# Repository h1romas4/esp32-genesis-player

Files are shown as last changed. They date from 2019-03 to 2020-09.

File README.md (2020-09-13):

# esp32-genesis-player

Work in progress..

## Demo

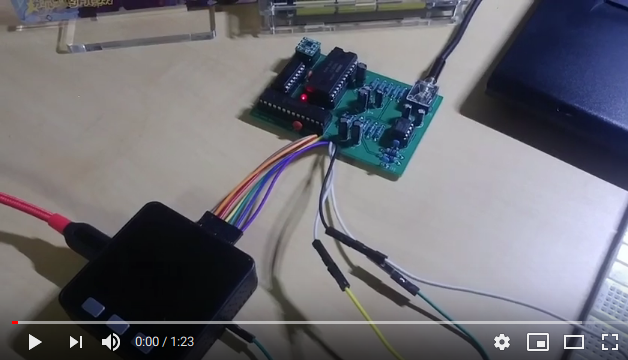
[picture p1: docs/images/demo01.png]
demo (https://youtu.be/mzKiQgvpdTA)


## Require

* ESP32 (ESP32-DevKitC, M5Stack...)
* [esp32-idf toolchain setup](https://docs.espressif.com/projects/esp-idf/en/stable/get-started/index.html#setup-toolchain)

```
$ xtensa-esp32-elf-gcc -v
gcc version 5.2.0 (crosstool-NG crosstool-ng-1.22.0-80-g6c4433a)
```

## Build



```
git clone  --recursive https://github.com/h1romas4/esp32-genesis-player.git
cd esp32-genesis-player
# This repository includes eps-idf v3.3.3
export IDF_PATH=$(pwd)/esp-idf
# Serial flasher config
make menuconfig
# compile & flash
make flash
```

## Upload .vgm file to esp32 flash

```
# mv example.vgz example.vgm.gz
# gzip -d example.vgm.gz
./flashrom.sh vgm/kanon2612.vgm
```

## Schematic

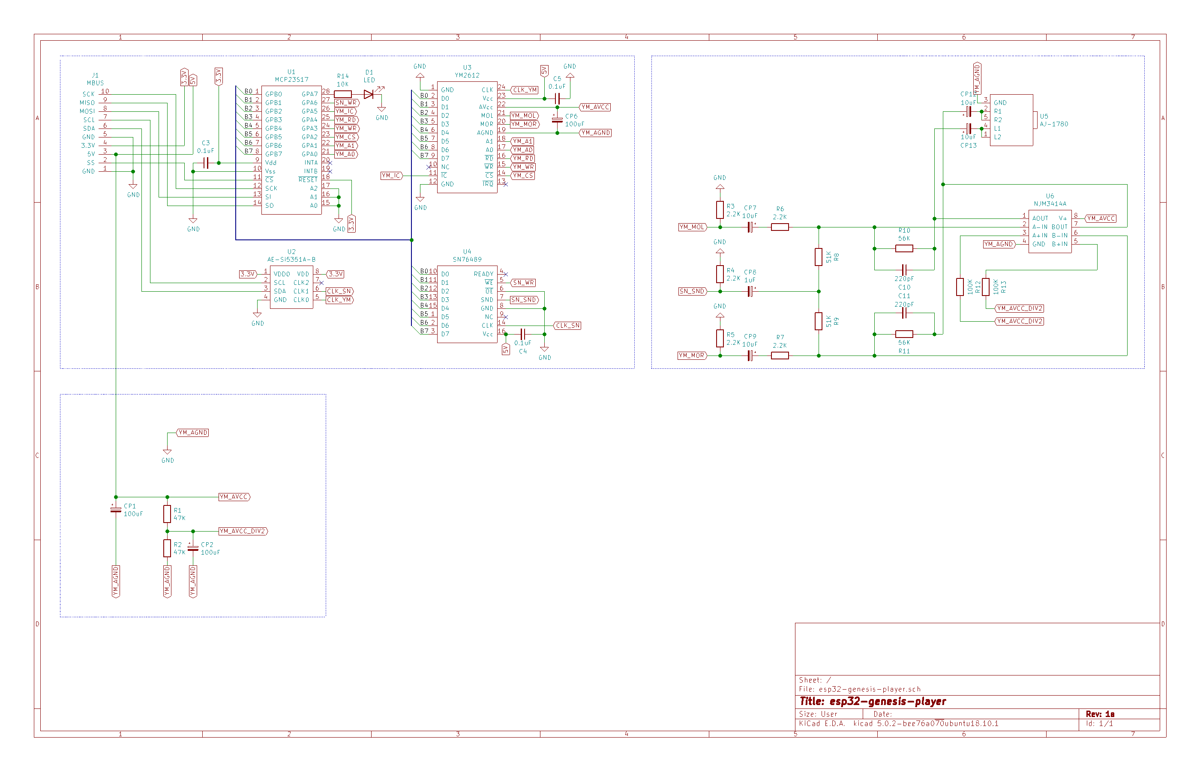
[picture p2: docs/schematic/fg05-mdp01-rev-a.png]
fg05-mdp01-rev-a


### ESP32 (MBUS)

```
ESP32 GPIO(23) VSPI MOSI     MCP23S17(13) SI
ESP32 GPIO(19) VSPI MISO     MCP23S17(14) SO
ESP32 GPIO(18) VSPI SCK      MCP23S17(12) SCK
ESP32 GPIO( 5) VSPI SS       MCP23S17(11) CS
ESP32 GPIO(22) SCL           Si5351A(2)  SCL
ESP32 GPIO(21) SDA           Si5351A(3)  SDA
```

### MCP23S17

```
IC( 9) Vdd             3.3V
IC(10) Vss             GND
IC(15) A0              GND
IC(16) A1              GND
IC(17) A2              GND
IC(18) RESET           3.3V
IC(19) INTA            (NC)
IC(29) INTB            (NC)
```

## Si5351A ([AE-Si5351A-B](http://akizukidenshi.com/catalog/g/gK-10679/))

```
DIP(1) VDD0            3.3V
DIP(4) GND             GND
DIP(7) CLK2            (NC)
DIP(8) VDD             3.3V
```

### YM2612

```
IC( 1) GND            GND
IC( 2) D0             MCP23S17( 1)  GPB0
IC( 3) D1             MCP23S17( 2)  GPB1
IC( 4) D2             MCP23S17( 3)  GPB2
IC( 5) D3             MCP23S17( 4)  GPB3
IC( 6) D4             MCP23S17( 5)  GPB4
IC( 7) D5             MCP23S17( 6)  GPB5
IC( 8) D6             MCP23S17( 7)  GPB6
IC( 9) D7             MCP23S17( 8)  GPB7
IC(10) NC             (NC)
IC(11) ~IC            MCP23S17(26)  GPA5
IC(12) GND            GND
IC(13) ~IRQ           (NC)
IC(14) ~CS            MCP23S17(23)  GPA2
IC(15) ~WR            MCP23S17(24)  GPA3
IC(16) ~RD            MCP23S17(25)  GPA4
IC(17) A0             MCP23S17(21)  GPA0
IC(18) A1             MCP23S17(22)  GPA1
IC(19) AGND           GND
IC(20) MOR            (audio R)
IC(21) MOL            (audio L)
IC(22) AVcc           5V - 100uf bypass capacitor
IC(23) Vcc            5V - 0.1uF bypass capacitor
IC(24) CLK            Si5351A(5) CLK0
```

### SN76489

```
IC( 1) D5             MCP23S17( 6)  GPB5
IC( 2) D6             MCP23S17( 7)  GPB6
IC( 3) D7             MCP23S17( 8)  GPB7
IC( 4) READY          (NC)
IC( 5) ~WE            MCP23S17(27)  GPA6
IC( 6) ~CE            GND
IC( 7) SNDOUT         (audio L/R)
IC( 8) GND            GND
IC( 9) NC             (NC)
IC(10) D0             MCP23S17( 1)  GPB0
IC(11) D1             MCP23S17( 2)  GPB1
IC(12) D2             MCP23S17( 3)  GPB2
IC(13) D3             MCP23S17( 4)  GPB3
IC(14) CLK            Si5351A(6) CLK1
IC(15) D4             MCP23S17( 5)  GPB4
IC(16) Vcc            5V
```

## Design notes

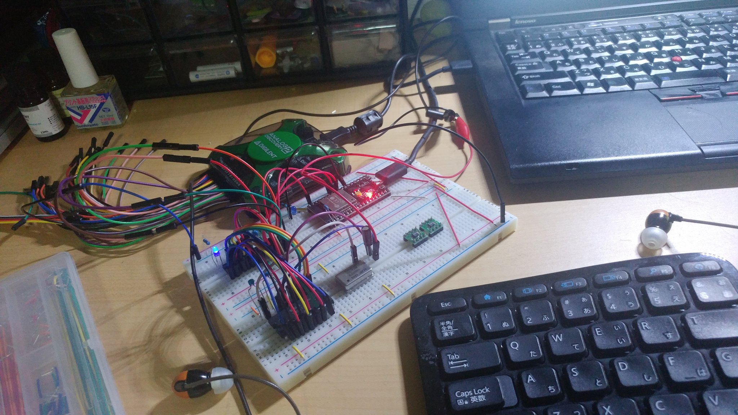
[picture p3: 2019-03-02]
docs/images/progress01.jpg

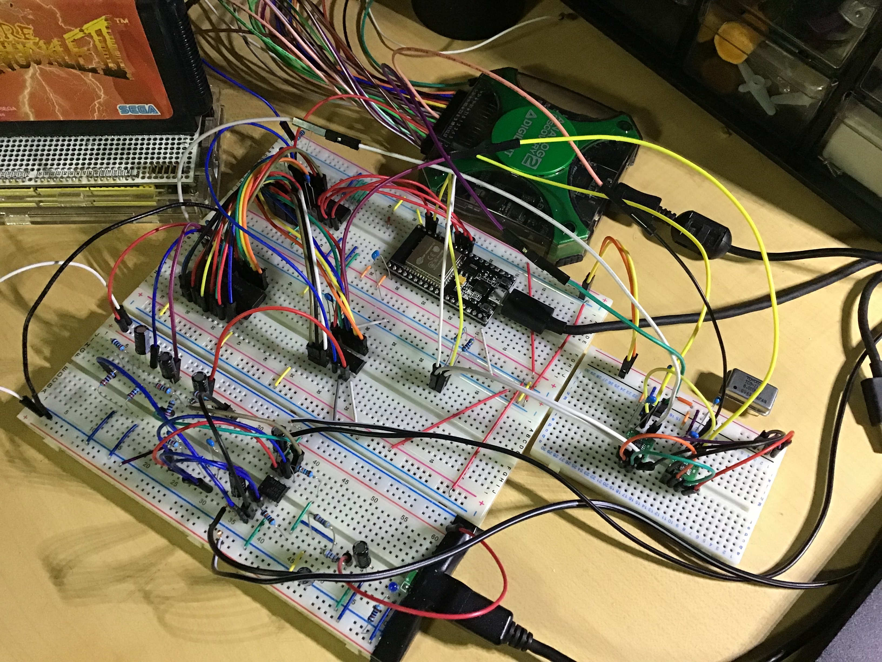
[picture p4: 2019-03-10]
docs/images/progress02.jpg

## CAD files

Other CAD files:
docs/blender/22uh.blend
docs/blender/30pin.blend
docs/blender/AJ-1780.blend
docs/blender/BNX016-01.blend
docs/blender/KMR-18.blend
docs/blender/TS-0606.blend
docs/blender/lock.blend

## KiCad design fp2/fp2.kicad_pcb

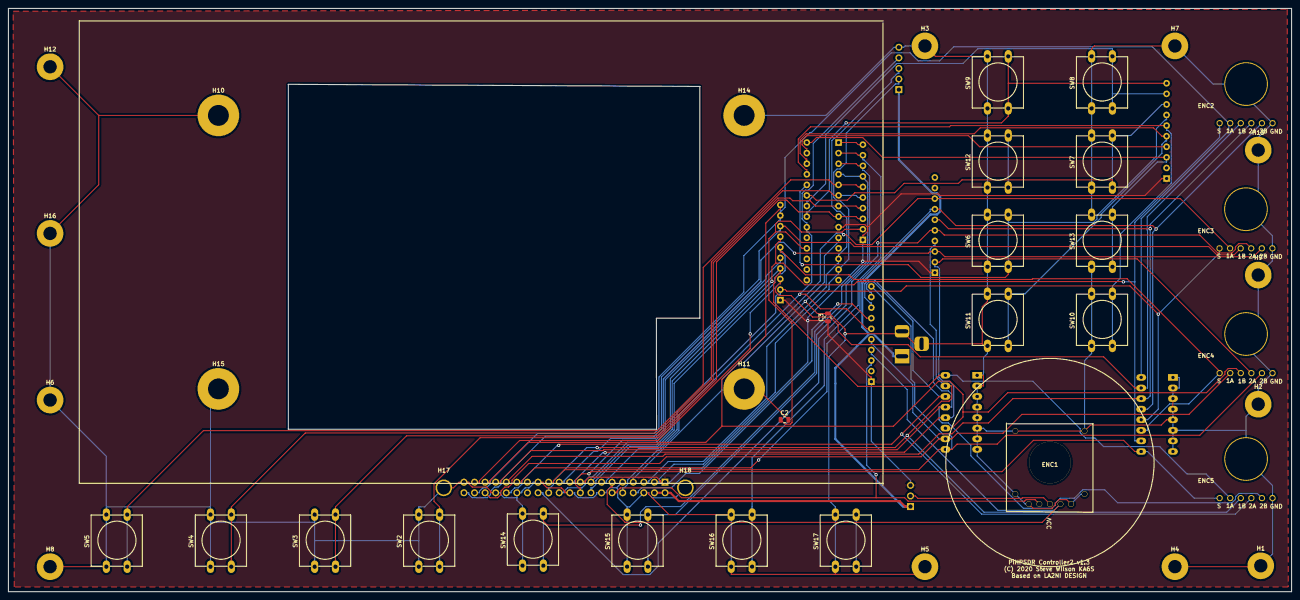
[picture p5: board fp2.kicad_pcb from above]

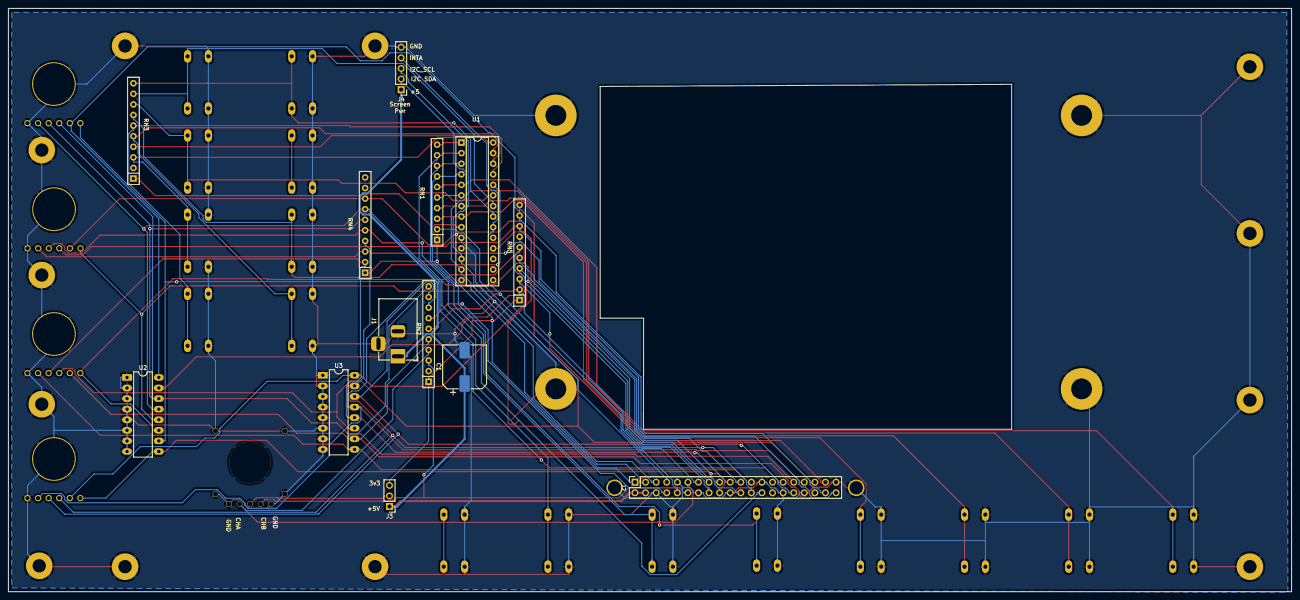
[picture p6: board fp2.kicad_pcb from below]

Board: 2 copper layers, 308.0 x 140.0 mm, 54 parts (13 on the bottom side), 47 nets.

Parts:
C1: 220uF; CP_Elec_10x10
C2: 0.01uF; C_0805_2012Metric
C3: 10uF; C_0805_2012Metric
ENC1: Rotary_Encoder_HRPG
ENC2, ENC3, ENC4, ENC5: rotary_encoder_elma37a; ELMA_E37A
H1, H2, H3, H4, H5, H6, H7, H8, H9, H12, H13, H16, H17, H18: MountingHole_Pad; MountingHole_3.2mm_M3_Pad
H10, H11, H14, H15: MountingHole_Pad; MountingHole_5mm_Pad
J1: Barrel_Jack_MountingPin; BarrelJack_Horizontal
J2: Conn_02x20_Odd_Even; PinSocket_2x20_P2.54mm_Vertical
J3: Conn_01x03; PinHeader_1x03_P2.54mm_Vertical
J4: Conn_01x05; PinHeader_1x05_P2.54mm_Vertical
RN1, RN2, RN3, RN4, RN5: 10K; R_Array_SIP10
SW2, SW3, SW4, SW5, SW6, SW7, SW8, SW9, SW10, SW11, SW12, SW13, SW14, SW15, SW16, SW17: SW_SPST; SW_PUSH-12mm
U1: MCP23017_SO; DIP-28_W7.62mm_Socket
U2, U3: 0.01uF ARRAY; CAP_ARRAY_16

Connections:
/encoder/3V3: C3.1, J2.1, J2.17, J3.3, RN1.1, RN2.1, RN3.1, RN4.1, RN5.1, U1.9
/encoder/5V: C1.1, J1.1, J2.2, J2.4, J3.1, J4.1
/encoder/GBP0: RN1.10, U1.1
/encoder/GPA0: RN3.10, SW9.2, U1.21
/encoder/GPA1: RN3.9, SW8.2, U1.22
/encoder/GPA2: RN3.8, SW7.2, U1.23
/encoder/GPA3: RN3.7, SW6.2, U1.24
/encoder/GPA4: RN3.6, SW10.2, U1.25
/encoder/GPA5: RN3.5, SW11.2, U1.26
/encoder/GPA6': RN3.4, U1.27
/encoder/GPA7: RN3.3, SW13.2, U1.28
/encoder/GPB1: RN1.9, SW16.2, U1.2
/encoder/GPB2: RN1.8, SW15.2, U1.3
/encoder/GPB3: RN1.7, SW14.2, U1.4
/encoder/GPB4: RN1.6, SW5.2, U1.5
/encoder/GPB5: RN1.5, SW4.2, U1.6
/encoder/GPB6: RN1.4, SW3.2, U1.7
/encoder/GPB7: RN1.3, SW2.2, U1.8
/encoder/GPIO4: ENC3.2, J2.7, RN4.8
/encoder/GPIO5: ENC2.5, J2.29, RN4.7, U2.13
/encoder/GPIO6: ENC2.4, J2.31, RN4.6, U2.14
/encoder/GPIO7: ENC3.4, J2.26, RN4.5
/encoder/GPIO8: ENC5.3, J2.24, RN4.4, U3.15
/encoder/GPIO9: ENC3.5, J2.21, RN4.3
/encoder/GPIO10: ENC4.4, J2.19, RN4.2, U3.12
/encoder/GPIO11: ENC4.5, J2.23, RN2.10, U3.9
/encoder/GPIO12: ENC5.4, J2.32, RN2.9, U3.14
/encoder/GPIO13: ENC5.5, J2.33, RN2.8, U3.13
/encoder/GPIO14: J2.8, RN2.7
/encoder/GPIO15: J2.10, J4.4, RN2.6, U1.20
/encoder/GPIO16: ENC4.2, J2.36, RN2.5, U3.10
/encoder/GPIO17: ENC1.2, J2.11, RN2.4
/encoder/GPIO18: ENC1.4, J2.12, RN2.3
/encoder/GPIO19: ENC4.3, J2.35, RN5.10, U3.11
/encoder/GPIO20: ENC2.2, J2.38, RN5.9, U2.16
/encoder/GPIO21: ENC3.3, J2.40, RN5.8
/encoder/GPIO22: ENC2.1, J2.15, RN5.7, U2.10
/encoder/GPIO23: ENC4.1, J2.16, RN5.6, U2.11
/encoder/GPIO24: ENC5.1, J2.18, RN5.5, U2.9
/encoder/GPIO25: ENC5.2, J2.22, RN5.4, U3.16
/encoder/GPIO26: ENC2.3, J2.37, RN5.3, U2.15
/encoder/GPIO27: ENC3.1, J2.13, RN5.2, U2.12
/encoder/I2C_SCL: J2.5, J4.3, U1.12
/encoder/I2C_SDA: J2.3, J4.2, U1.13
GND: C1.2, C2.2, C3.2, ENC1.1, ENC1.5, ENC2.6, ENC3.6, ENC4.6, ENC5.6, H1.1, H2.1, H3.1, H4.1, H5.1, H6.1, H7.1, H8.1, H9.1, H10.1, H11.1, H12.1, H13.1, H14.1, H15.1, H16.1, H17.1, H18.1, J1.2, J1.MP, J2.6, J2.9, J2.14, J2.20, J2.25, J2.30, J2.34, J2.39, J4.5, SW2.1, SW3.1, SW4.1, SW5.1, SW6.1, SW7.1, SW8.1, SW9.1, SW10.1, SW11.1, SW12.1, SW13.1, SW14.1, SW15.1, SW16.1, SW17.1, U1.10, U2.1, U2.2, U2.3, U2.4, U2.5, U2.6, U2.7, U2.8, U3.1, U3.2, U3.3, U3.4, U3.5, U3.6, U3.7, U3.8
unnamed: C2.1, RN1.2, U1.18
unnamed: ENC1.3, J3.2

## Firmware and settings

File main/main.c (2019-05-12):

#include <string.h>
#include "freertos/FreeRTOS.h"
#include "freertos/task.h"
#include "nvs_flash.h"
#include "esp_system.h"
#include "esp_log.h"
#include "esp_partition.h"
#include "esp_heap_caps.h"
#include "esp_timer.h"
#include "chips.h"

// for vscode c_cpp_extention
#ifdef __INTELLISENSE__
#include "build/include/sdkconfig.h"
#endif

#define SAMPLE_RATE 44100.0

static const char *TAG = "vgmplay";

// uint8_t *vgm;
uint8_t *vgm;
uint32_t vgmpos = 0x40;
bool vgmend = false;
uint32_t vgmloopoffset;
uint32_t datpos;
uint32_t pcmpos;
uint32_t pcmoffset;
uint32_t pcmlength = 0;

int64_t startTime;
int64_t duration;
uint32_t delay8n[16];
uint32_t delay7n[16];

int64_t startTimePCM;
int64_t durationPCM;

void load_vgmdata()
{
    uint8_t *data;
    const esp_partition_t *part;
    spi_flash_mmap_handle_t hrom;
    esp_err_t err;

    nvs_flash_init();

    part = esp_partition_find_first(ESP_PARTITION_TYPE_DATA, ESP_PARTITION_SUBTYPE_DATA_PHY, NULL);
    if (part == 0) {
        ESP_LOGE(TAG, "Couldn't find vgm part!");
    }

    err = esp_partition_mmap(part, 0, 0x1EF000, SPI_FLASH_MMAP_DATA, (const void **)&data, &hrom);
    if (err != ESP_OK) {
        ESP_LOGE(TAG, "Couldn't map vgm part!");
    }
    ESP_LOGI(TAG, "read vgm data @%p", data);

    // // for testing..
    // vgm = (uint8_t *)heap_caps_malloc(100000 * sizeof(uint8_t), MALLOC_CAP_8BIT);
    // if(vgm == NULL) {
    //     ESP_LOGE(TAG, "Memory alloc error");
    // }
    // memcpy(vgm, data, 100000);
    // // vgm = (uint8_t *)data;

    vgm = (uint8_t *)data;
}

uint8_t get_vgm_ui8()
{
    return vgm[vgmpos++];
}

uint16_t get_vgm_ui16()
{
    return get_vgm_ui8() + (get_vgm_ui8() << 8);
}

uint32_t get_vgm_ui32()
{
    return get_vgm_ui8() + (get_vgm_ui8() << 8) + (get_vgm_ui8() << 16) + (get_vgm_ui8() << 24);
}

void init_vgm(chips_t *chips)
{
    uint32_t clock_sn76489;
    uint32_t clock_ym2612;

    // load vgm data
    load_vgmdata();

    // read vgm header
    vgmpos = 0x0C; clock_sn76489 = get_vgm_ui32();
    vgmpos = 0x2C; clock_ym2612 = get_vgm_ui32();
    vgmpos = 0x1c; vgmloopoffset = get_vgm_ui32();
    vgmpos = 0x34; vgmpos = 0x34 + get_vgm_ui32();

    if (clock_ym2612 == 0) clock_ym2612 = 7670453;
    if (clock_sn76489 == 0) clock_sn76489 = 3579545;

    chips->clock_ym2612 = clock_ym2612;
    chips->clock_sn76489 = clock_sn76489;

    ESP_LOGI(TAG, "clock_sn76489 : %d", clock_sn76489);
    ESP_LOGI(TAG, "clock_ym2612 : %d", clock_ym2612);
    ESP_LOGI(TAG, "vgmpos : 0x%x", vgmpos);

    // pre calc delay sample.
    for (int i = 0; i < 16; i++) {
        if (i == 0) {
            delay8n[i] = 0;
            delay7n[i] = 1;
        } else {
            delay8n[i] = ((1000.0 / (SAMPLE_RATE / (float)i)) * 1000);
            // +1 is spec-accurate; however, on this hardware, it sounds better without it.
            delay7n[i] = ((1000.0 / (SAMPLE_RATE / (float)i + 1)) * 1000);
        }
    }
}

void pause(uint32_t samples)
{
    duration = ((1000.0 / (SAMPLE_RATE / (float)samples)) * 1000);
    startTime = esp_timer_get_time();
}

void pause_ms(uint32_t ms)
{
    duration = ms;
    startTime = esp_timer_get_time();
}

void pause_pcm(uint32_t samples)
{
    durationPCM = ((1000.0 / (SAMPLE_RATE / (float)samples)) * 1000);
    startTimePCM = esp_timer_get_time();
}

void play_vgm()
{
    uint8_t command;
    uint8_t reg;
    uint8_t dat;

    // TODO: mucomMD2vgm hack
    if(pcmlength > 0 && esp_timer_get_time() - startTimePCM > durationPCM) {
        pause_pcm(5.5125);
        YM2612_Write(0, 0x2a);
        YM2612_Write(1, vgm[datpos + pcmpos + pcmoffset]);
        pcmoffset++;
        pcmlength--;
    }

    // wait play
    if (esp_timer_get_time() - startTime <= duration) {
        return;
    }

    command = get_vgm_ui8();
    switch (command) {
        case 0x50:
            dat = get_vgm_ui8();
            SN76489_Write(dat);
            break;
        case 0x52:
        case 0x53:
            reg = get_vgm_ui8();
            dat = get_vgm_ui8();
            YM2612_Write(0 + ((command & 1) << 1), reg);
            YM2612_Write(1 + ((command & 1) << 1), dat);
            break;
        case 0x61:
            pause(get_vgm_ui16());
            break;
        case 0x62:
            pause(735);
            break;
        case 0x63:
            pause(882);
            break;
        case 0x66:
            if(vgmloopoffset == 0) {
                vgmend = true;
            } else {
                vgmpos = vgmloopoffset;
            }
            break;
        case 0x67:
            get_vgm_ui8(); // 0x66
            get_vgm_ui8(); // 0x00 data type
            datpos = vgmpos + 4;
            vgmpos += get_vgm_ui32(); // size of data, in bytes
            break;
        case 0x70:
        case 0x71:
        case 0x72:
        case 0x73:
        case 0x74:
        case 0x75:
        case 0x76:
        case 0x77:
        case 0x78:
        case 0x79:
        case 0x7a:
        case 0x7b:
        case 0x7c:
        case 0x7d:
        case 0x7e:
        case 0x7f:
            pause_ms(delay7n[command & 0x0f]);
            break;
        case 0x80:
        case 0x81:
        case 0x82:
        case 0x83:
        case 0x84:
        case 0x85:
        case 0x86:
        case 0x87:
        case 0x88:
        case 0x89:
        case 0x8a:
        case 0x8b:
        case 0x8c:
        case 0x8d:
        case 0x8e:
        case 0x8f:
            pause_ms(delay8n[command & 0x0f]);
            YM2612_Write(0, 0x2a);
            YM2612_Write(1, vgm[datpos + pcmpos + pcmoffset]);
            pcmoffset++;
            break;
        case 0x90:
            // Setup Stream Control
            // TODO: mucomMD2vgm hack
            // 0x90 ss tt pp cc
            // 0x90 00 02 00 2a
            get_vgm_ui32();
            break;
        case 0x91:
            // Set Stream Data
            // TODO: mucomMD2vgm hack
            // 0x91 ss dd ll bb
            // 0x91 00 00 01 2a
            get_vgm_ui32();
            break;
        case 0x92:
            // Set Stream Frequency
            // TODO: mucomMD2vgm hack
            // 0x92 ss ff ff ff ff
            // 0x92 00 40 1f 00 00 (8KHz)
            get_vgm_ui8();
            get_vgm_ui32();
            break;
        case 0x93:
            // Start Stream
            // TODO: mucomMD2vgm hack
            // 0x93 ss aa aa aa aa mm ll ll ll ll
            // 0x93 00 aa aa aa aa 01 ll ll ll ll
            get_vgm_ui8();
            pcmpos = get_vgm_ui32();
            get_vgm_ui8();
            pcmlength = get_vgm_ui32();
            pcmoffset = 0;
            // 8KHz
            pause_pcm(5.5125);
            break;
        case 0xe0:
            pcmpos = get_vgm_ui32();
            pcmoffset = 0;
            break;
        default:
            ESP_LOGE(TAG, "unknown cmd at 0x%x: 0x%x", vgmpos - 1, command);
            vgmpos++;
            break;
    }
}

// The setup routine runs once when M5Stack starts up
void setup()
{
    chips_t chips;

    // Initialize VGM data
    init_vgm(&chips);

    // Initialize chips
    init_chips(&chips);

    ESP_LOGI(TAG, "Start VGM! (0x%x)", vgmpos);
    while (!vgmend) {
        play_vgm();
    }
    ESP_LOGI(TAG, "End VGM! (0x%x)", vgmpos);
}

// The loop routine runs over and over again forever
void loop()
{
}

// The arduino task
void loopTask(void *pvParameters)
{
    setup();
    for (;;) {
        esp_timer_get_time(); // update overflow
        loop();
    }
}

void app_main()
{
    xTaskCreatePinnedToCore(loopTask, "loopTask", 8192, NULL, 1, NULL, 1);
}

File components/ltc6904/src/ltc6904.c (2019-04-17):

#include <math.h>
#include "freertos/FreeRTOS.h"
#include "freertos/FreeRTOSConfig.h"
#include "freertos/portmacro.h"
#include "driver/i2c.h"
#include "soc/gpio_sig_map.h"
#include "soc/i2c_struct.h"
#include "soc/i2c_reg.h"
#include "esp_system.h"
#include "esp_log.h"
#include "ltc6904.h"

// for vscode c_cpp_extention
#ifdef __INTELLISENSE__
#include "build/include/sdkconfig.h"
#endif

#define ACK_CHECK_EN  0x1 /*!< I2C master will check ack from slave*/
#define ACK_CHECK_DIS 0x0 /*!< I2C master will not check ack from slave */

static const char* TAG = "ltc6904.c";

ltc6904_err_t ltc6904_init()
{
    ESP_LOGI(TAG, "ltc6904 init start.");

	esp_err_t ret;
	i2c_config_t conf = {
		.mode = I2C_MODE_MASTER,
		.sda_io_num = GPIO_NUM_21,
		.scl_io_num = GPIO_NUM_22,
		.sda_pullup_en = GPIO_PULLUP_DISABLE,
		.scl_pullup_en = GPIO_PULLUP_DISABLE,
		.master.clk_speed = 100000
	};
	ret = i2c_param_config(I2C_NUM_0, &conf);

	if(ret != ESP_OK) {
		ESP_LOGE(TAG,"PARAM CONFIG FAILED");
		return LTC6904_ERR_CONFIG;
	}

	// install the driver
	ret = i2c_driver_install(I2C_NUM_0, I2C_MODE_MASTER, 0, 0, 0);
	if(ret != ESP_OK) {
		ESP_LOGE(TAG,"I2C driver install failed");
		return LTC6904_ERR_INSTALL;
	}

    ESP_LOGI(TAG, "ltc6904 init end.");

    return LTC6904_ERR_OK;
}

ltc6904_err_t ltc6904_write(uint8_t addr, uint16_t code)
{
    uint8_t high = (uint8_t)((code & 0xff00) >> 8);
    uint8_t low = (uint8_t)(code & 0x00ff);

    i2c_cmd_handle_t cmd = i2c_cmd_link_create();
    i2c_master_start(cmd);
    i2c_master_write_byte(cmd, addr << 1 | I2C_MASTER_WRITE, ACK_CHECK_EN);
    i2c_master_write_byte(cmd, high, ACK_CHECK_EN);
    i2c_master_write_byte(cmd, low, ACK_CHECK_EN);
    i2c_master_stop(cmd);
    esp_err_t ret = i2c_master_cmd_begin(I2C_NUM_0, cmd, 1000 / portTICK_PERIOD_MS);
    i2c_cmd_link_delete(cmd);
    if (ret == ESP_FAIL) {
        ESP_LOGE(TAG,"ERROR: unable to write to register");
        return LTC6904_ERR_FAIL;
    }
    return LTC6904_ERR_OK;
}

// https://github.com/jakeson21/Arduino-LTC6904-Library/blob/141e5b5b3b3a6c10d6aeac080a59335e6d1741e8/LTC6904.cpp
ltc6904_err_t ltc6904_set_clock(uint8_t addr, float freq_mhz)
{
    ltc6904_err_t ret;

    uint8_t oct;
    double oct_double;
    float float_dac;
    uint16_t dac;

    // Calculate OCT
    oct_double = log10((double)((freq_mhz * 1000000) / 1039));
    oct_double *= 3.322;

    // Keep OCT within range
    if(oct_double > 15) oct = 15;
    if(oct_double < 0) oct = 0;
    oct = (uint8_t)oct_double; // Cast as uint8_t , round down

    // Calculate DAC code
    float_dac = 2048 - (2078 * pow(2, (10 + oct))) / (freq_mhz * 1000000); // Calculate the dac code
    float_dac = (float_dac > (floor(float_dac) + 0.5)) ? ceil(float_dac) : floor(float_dac); // Round

    // Keep DAC within range
    if(float_dac > 1023) float_dac = 1023;
    if(float_dac < 0) float_dac = 0;

    dac = (uint16_t)float_dac;  // Cast as uint16_t

    ret = ltc6904_write(addr, (uint16_t)((oct<<12) | (dac<<2)));

    ESP_LOGI(TAG, "ltc6904 : %x", (uint16_t)((oct<<12) | (dac<<2)));

    return ret;
}

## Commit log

2019-03-10 add schematic
2019-03-11 fix spi buffer
2019-04-28 add sample vgm file.
2020-09-19 add initial PCB (rev2)
    [genesis-sound-card-rev2.kicad_pcb, genesis-sound-card-rev2.sch]
2020-09-21 add 3D models
    [AJ-1780.blend, BNX016-01.blend]
2020-10-31 add TS-0606 model
    [TS-0606.blend]
2021-02-23 add 3d model
    [30pin.blend]
2021-03-14 add model
    [22uh.blend, lock.blend]
2021-12-20 add module
    [KMR-18.blend]
2021-12-20 add pcb
    [genesis-sound-card-rev2-B_Cu.gbl, genesis-sound-card-rev2-B_Mask.gbs, genesis-sound-card-rev2-B_Paste.gbp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]
